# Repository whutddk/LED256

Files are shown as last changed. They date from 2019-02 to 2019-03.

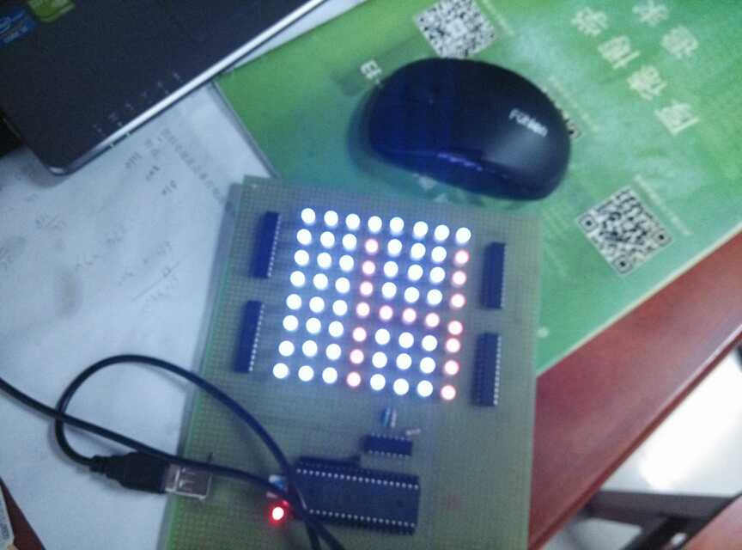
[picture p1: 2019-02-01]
pic/微信图片_2019013121595619.jpg

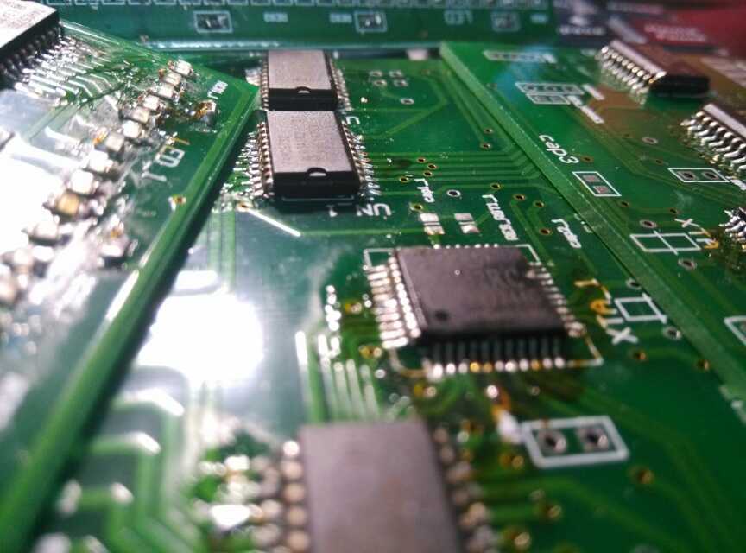
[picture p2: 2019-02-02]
pic/微信图片_2019013121595618.jpg

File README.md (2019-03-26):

# LED256

* 大一下学期，学院，科协举办第一届流水灯大赛

## 全彩点阵(第二名)
* 当时比赛时学长指出，这是真彩，不是全彩

* 大一和几个同学参加学院流水灯大赛的作品代码，拼命榨干了51单片机的资源
* 虽已经历很多全国赛事，依然觉得当时这代码和方案写得不错。
* 方案
    - 颜色控制
        + 使用三色雾状灯冒LED，共阴引脚。
        + 当时pwm控制颜色的技术不是很成熟，也尝试过了，最终采用I2C控制下的DAC（***TLC5620）***控制颜色的方案：将64个灯的红色阳极接在一起，接到DAC的*chn0*；将64个灯的绿色阳极接在一起，接到DAC的*chn1*；将64个灯的蓝色阳极接在一起，接到DAC的*chn2*
        + 通过控制DAC的输出电压，分别控制每个灯的颜色。
    - 图案控制
        + 扫描技术，视觉暂留原理
        + 使用多个译码器（74hc138，74HC154）组合后逐个扫描64个灯的阴极。
    - 控制
        + 51单片机，原型验证用的是STC89C52，后面ROM，速度告急，在宏晶官网找了一款引脚完全兼容，，节拍更快的型号换上去，把晶振速度换大。
        + 多个定时器和延时调度
            * 无源蜂鸣器播放音乐
            * 刷新颜色，消隐
            * 保持图片，换图
    - 刷图大致流程
    ```
         for (imageCnt = 0 ;imageCnt < ? ;imageCnt ++):                         // 选图
         
               for (imageDelayCnt = 0;imageDelayCnt < ? ; imageDelayCnt ++ ):   // 每张图多刷几次延时以保证视觉暂留能看到
               
                   for ( lightCnt = 0 ; lightCnt < 64; lightCnt ++ ):           // 扫描64个灯进行视觉暂留
                   
                       decoder select (lightCnt)                                // 选灯
                       
                       DAC set color (red,green,blue)                           // 输出颜色
                       
                       __nop__(3);                                              // 保持
                       
                       DAC set color (0,0,0)                                    //消影

### Contributors
* Xiangjie Wu
* Songhuan Huang
* Wentao Sun
* Ruige Lee

---------------------------------------------------------------

## 风火轮（第一名）
* 做完摇摇棒，就想到了把摇摇棒安装在自行车的车轮上，转起来，一个图案
* 采用霍尔传感器，需要在车轮上贴一个磁铁标记起始位置
* 每次检测到磁铁后，开始刷图案，因为自行车加速度不是很大，默认车轮每圈所用时间为上一圈的时间，则可以计算出图片每个位置开始时间

* [申请了实用新型专利](http://www.wanfangdata.com.cn/details/detail.do?_type=patent&id=CN201620157427.7)

### Contributors
* Pu Liu
* Zong Yang
* Ruige Lee

## 图片
* 风火轮原型
    - ![风火轮原型](https://github.com/whutddk/LED256/blob/master/pic/微信图片_2019013121595610.jpg)
* 风火轮成品
    -　![风火轮成品](https://github.com/whutddk/LED256/blob/master/pic/IMG_20140502_124040.jpg)
*　风火轮效果
    -　![风火轮效果](https://github.com/whutddk/LED256/blob/master/pic/IMG_20140207_230420_SHOT2SHOT20.jpg)
* 真彩点阵原型
    -　![真彩点阵原型](https://github.com/whutddk/LED256/blob/master/pic/微信图片_2019013121595616.jpg)
* 真彩点阵成品
    -　![真彩点阵成品](https://github.com/whutddk/LED256/blob/master/pic/微信图片_2019013121595619.jpg)
* 真彩点阵效果
    -　![真彩点阵效果](https://github.com/whutddk/LED256/blob/master/pic/2014_10_11_22_08_57.jpg)

## 视频
* 请参考作品视频链接，因拍摄问题，视频看起来没有实际鲜艳
* [风火轮原型版本](https://v.qq.com/x/page/k0127j38gix.html?)
* [风火轮比赛版本](https://v.youku.com/v_show/id_XMzc3ODE3ODQxNg==.html?spm=a2hzp.8244740.0.0)
* [真彩点阵](http://v.youku.com/v_show/id_XMzc3ODE3NDk5Mg==.html?spm=a2h3j.8428770.3416059.1)

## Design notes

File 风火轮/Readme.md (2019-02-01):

# 风火轮

* 大一下学期
* 个人的第一块pcb
* 风火轮应该要单独建仓
* 挺怀念那时，第一次去鉴湖实验室，柳老板教我画板子，真的很感谢学长

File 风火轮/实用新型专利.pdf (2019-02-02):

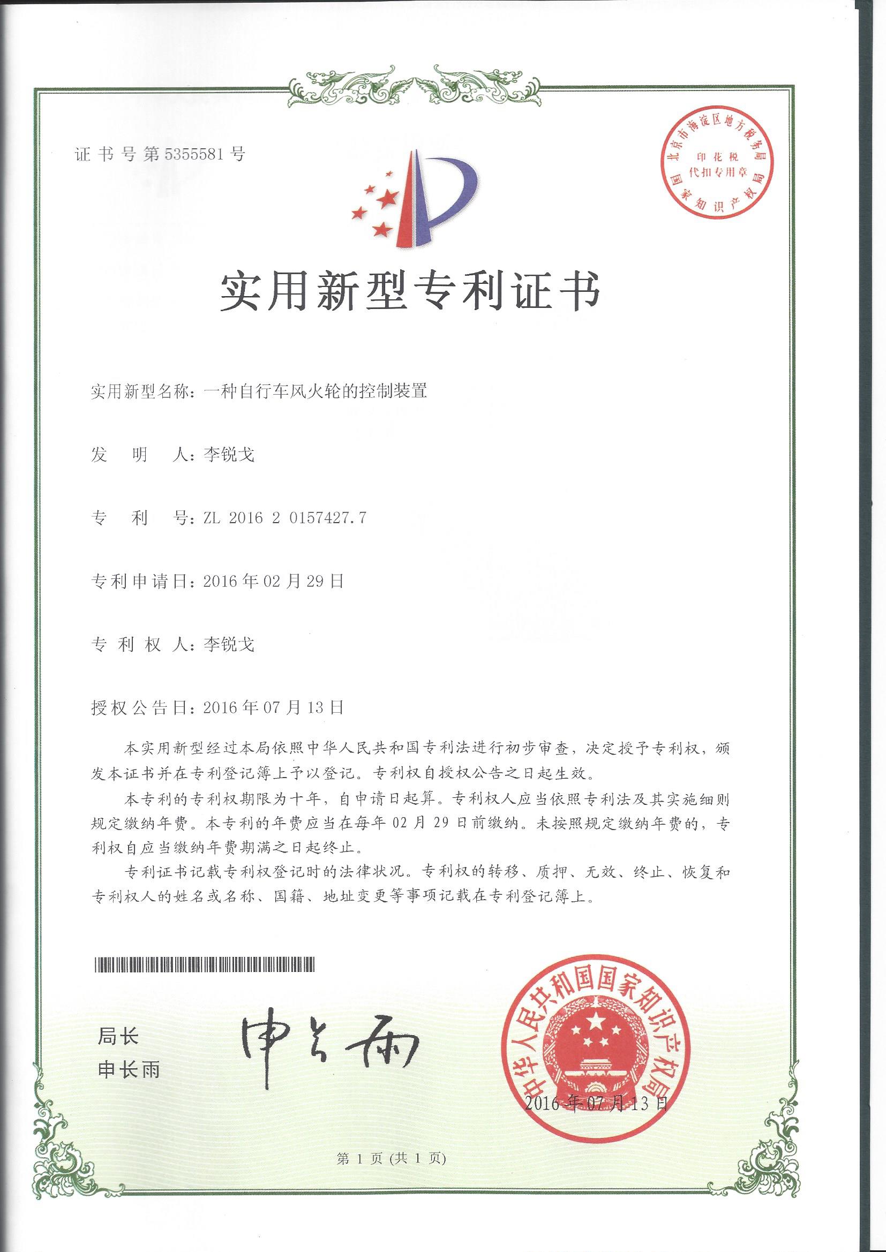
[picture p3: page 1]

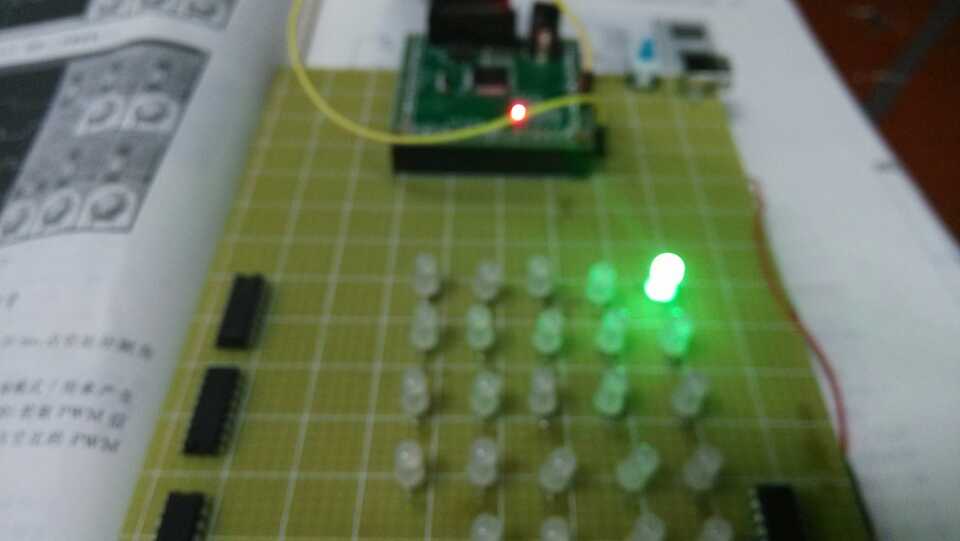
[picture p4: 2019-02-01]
pic/微信图片_2019013121595614.jpg

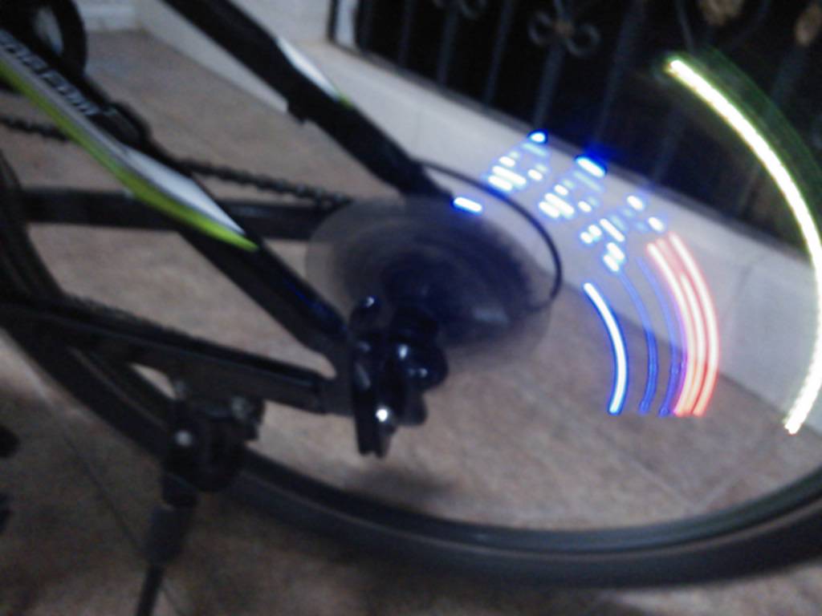
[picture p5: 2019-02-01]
pic/IMG_20140205_215553_SHOT2SHOT3.jpg

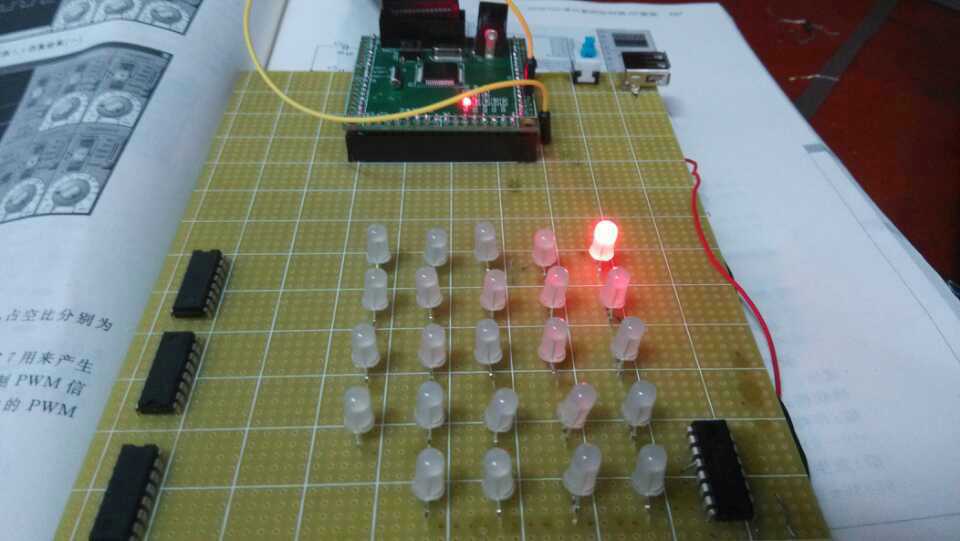
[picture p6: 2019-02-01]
pic/微信图片_2019013121595613.jpg

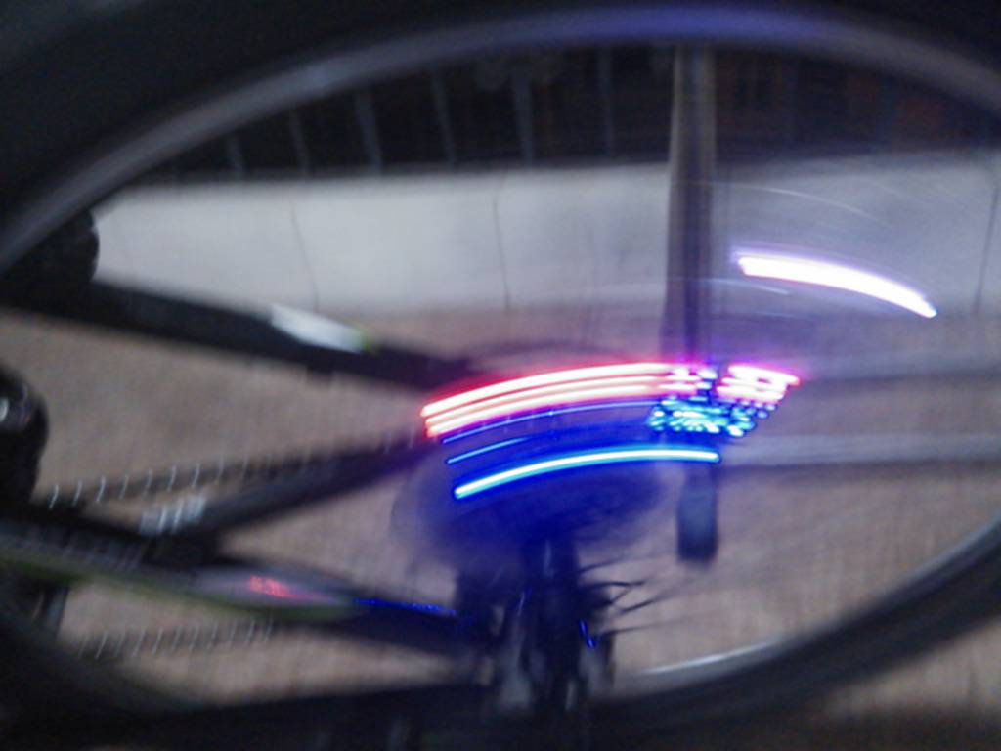
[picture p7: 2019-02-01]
pic/IMG_20140204_225233_SHOT2SHOT19.jpg

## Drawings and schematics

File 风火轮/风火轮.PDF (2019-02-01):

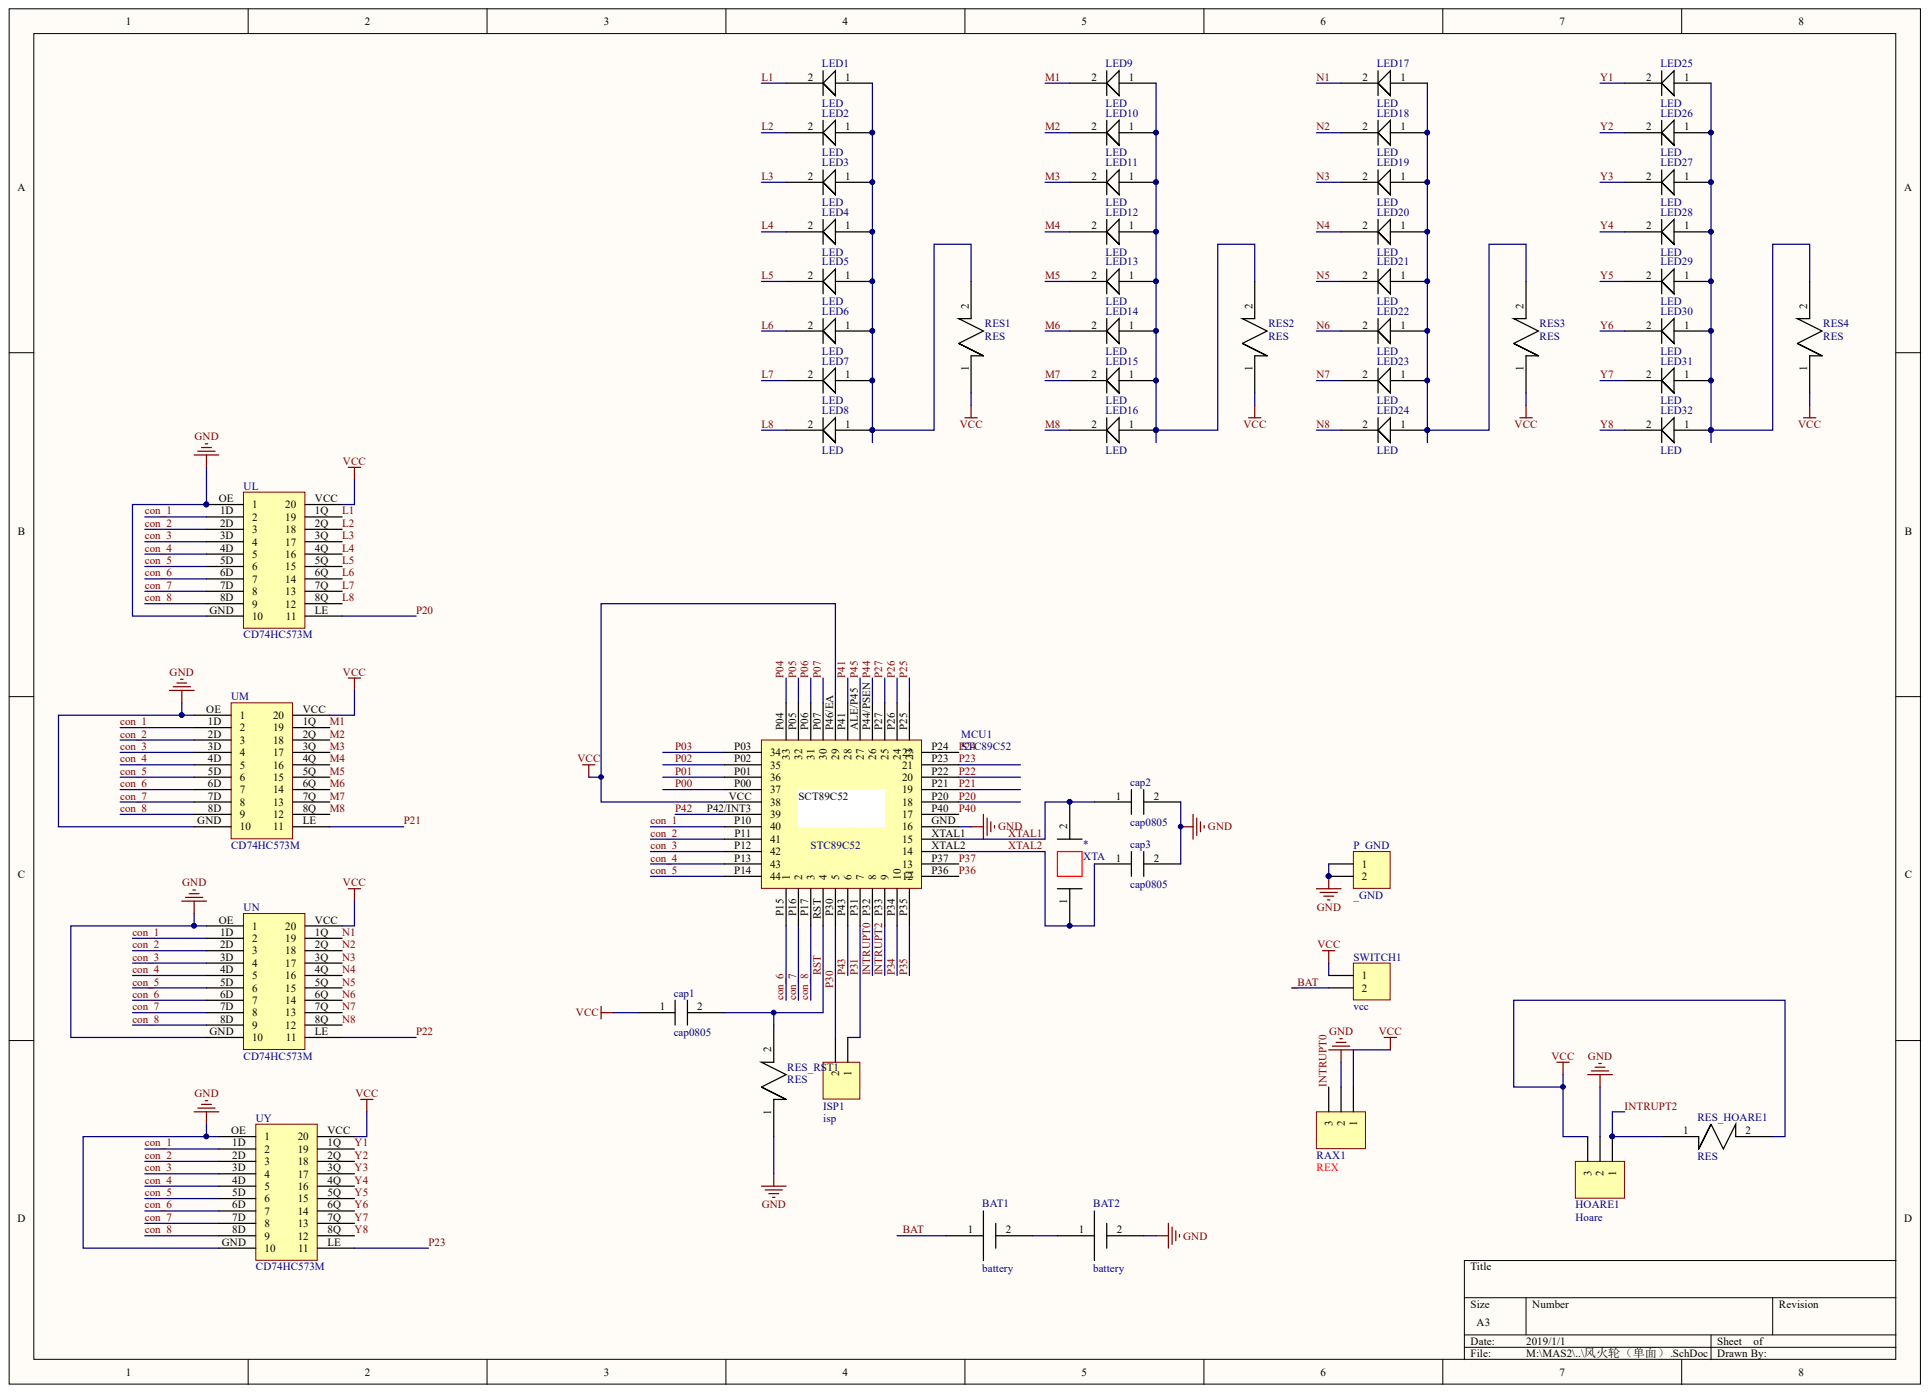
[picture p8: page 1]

11 P35 12 P36 13 P37 14 XTAL2 15 XTAL1 16 GND 17 P40 18 P20 19 P21 20 P22 21 P23 22 P24 23 P25 24 P26 25 P27 26 P44/PSEN 27 ALE/P45 28 P41 29 P46/EA 30 P07 31 P06 32 P05 33 P04

34 P03 35 P02 36 P01 37 P00 38 VCC

SCT89C52

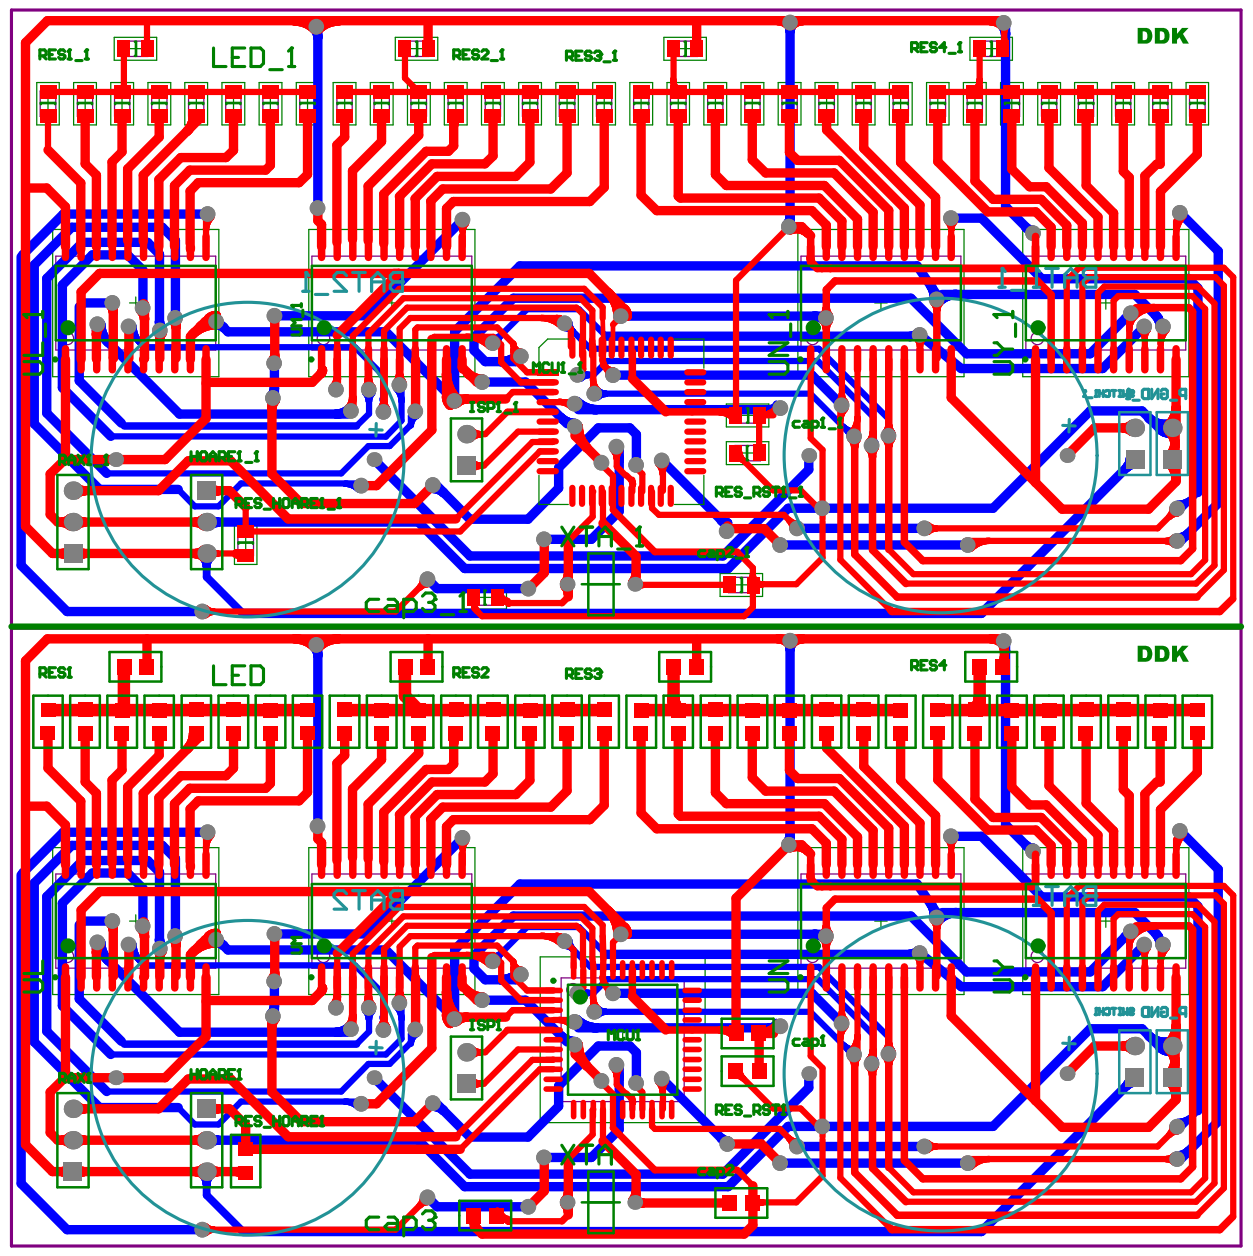
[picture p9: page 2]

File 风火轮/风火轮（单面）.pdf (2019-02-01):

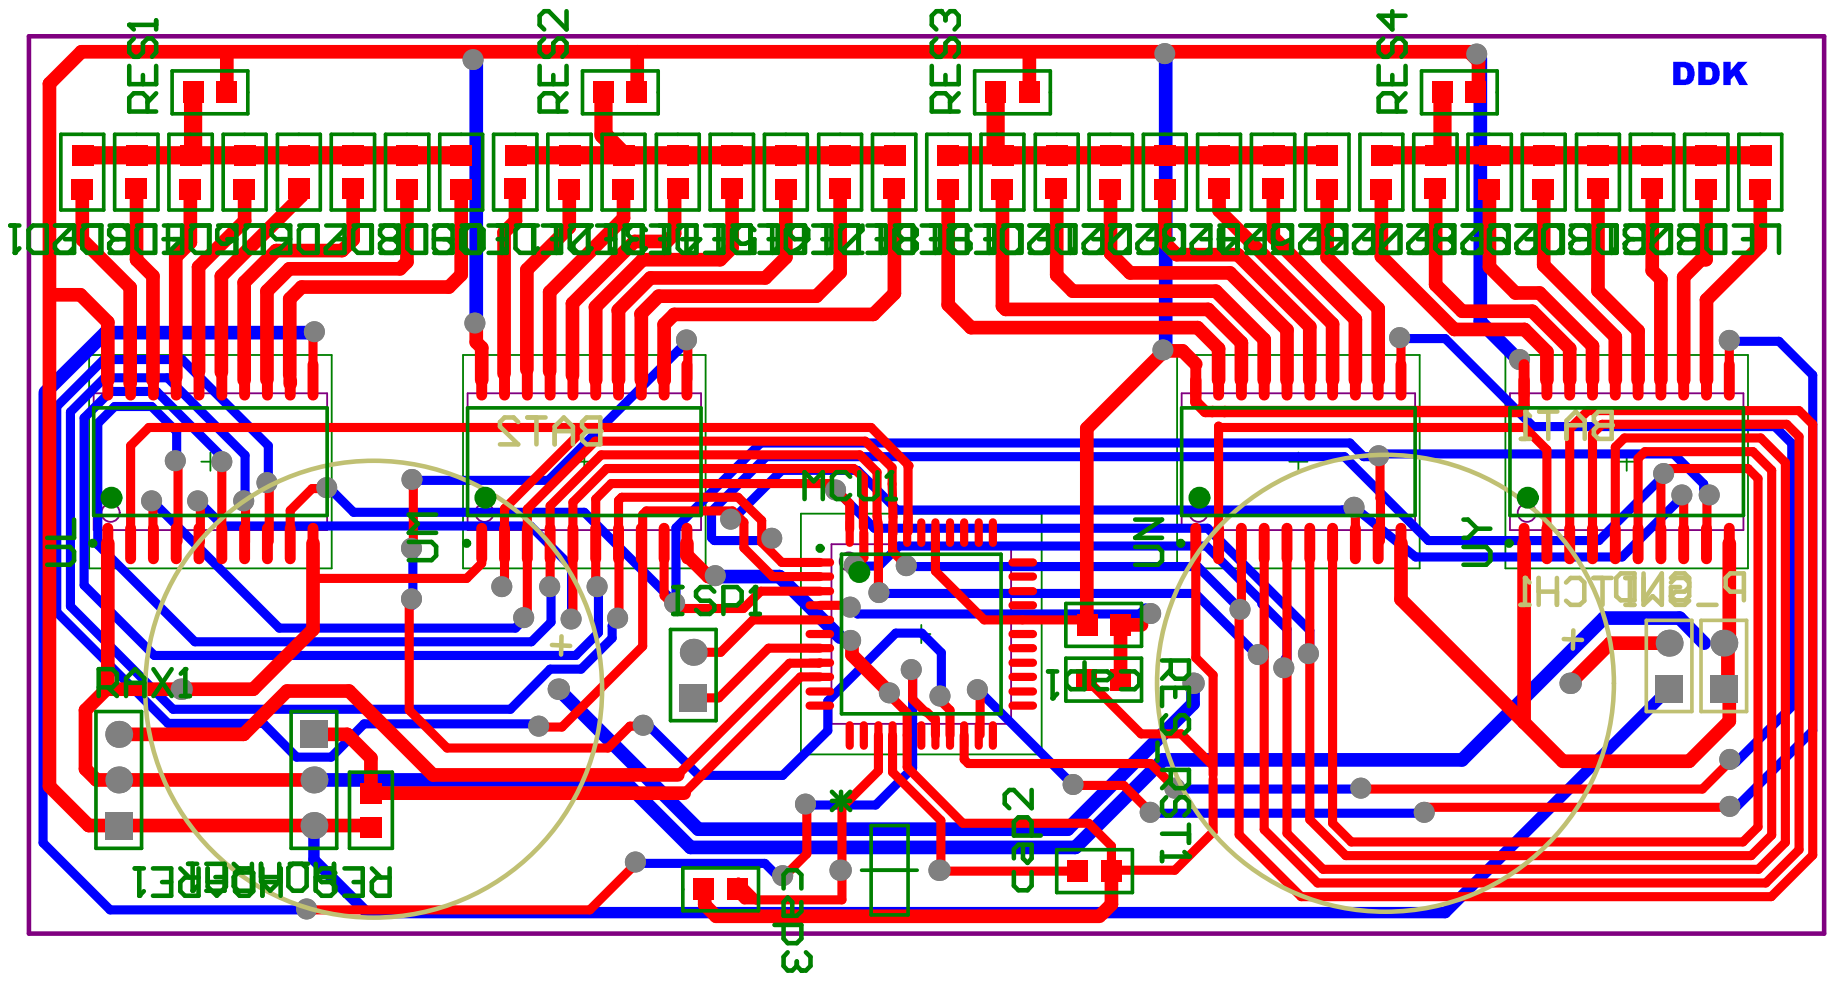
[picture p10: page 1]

Bill of Materials | <Parameter Title not found>
Source Data From: | 风火轮（单面）.PrjPcb
Project: | | 风火轮（单面）.PrjPcb
Variant: | | None
Creation Date: 2014/4/20 | 16:10:09
Print Date: | 41749 | 41749.67381
Footprint | Comment | LibRef | Designator | Description | Quantity
TIMER | XTA | XTA | | | 1
纽扣电池 | battery | battery | BAT1, BAT2 | | 2
0805（1） | cap0805 | cap0805 | cap1, cap2, cap3 | | 3
HDR1X3 | Hoare | Header 3 | HOARE1 | Header, 3-Pin | 1
HDR1X2 | isp | Header 2 | ISP1 | Header, 2-Pin | 1
0805（1） | LED | led0805 | LED1, LED2, LED3, LED4, LED5, LED6,
| | | LED7, LED8, LED9, LED10, LED11,
| | | LED12, LED13, LED14, LED15, LED16,
| | | LED17, LED18, LED19, LED20, LED21,
| | | LED22, LED23, LED24, LED25, LED26,
| | | LED27, LED28, LED29, LED30, LED31,
| | | LED32 | | 32

QFP127P600
8N_LQFP889
C52
STC89C52 | STC89C52 | MCU1 | 1
HDR1X2 | _GND | Header 2 | P_GND | Header, 2-Pin | 1
HDR1X3 | REX | Header 3 | RAX1 | Header, 3-Pin | 1
0805（1） | RES | res0805 | RES1, RES2, RES3, RES4,
| | | RES_HOARE1, RES_RST1 | | 6
HDR1X2 | vcc | Header 2 | SWITCH1 | Header, 2-Pin | 1
SOIC127P10
30X265-
20N_CD74H
C573M_SOIC
| CD74HC573M | CD74HC573M | UL, UM, UN, UY | | 4

54
Approved | Notes

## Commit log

2019-01-07 Update README.md
    居然有人看，谢谢关注，加入视频链接
2019-02-01 加入风火轮版本，未完成
    [风火轮.PcbDoc, 风火轮（单面）.PcbDoc, 风火轮（单面）.PrjPcb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]
2019-02-02 基本完成整理
    [风火轮.PcbDoc]
2019-02-02 pic 调整
